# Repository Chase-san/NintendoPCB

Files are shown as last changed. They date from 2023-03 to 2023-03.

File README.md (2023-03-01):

# NintendoPCB

This repository is for the reproduction and documentation of various Nintendo PCBs. Specifically targeting the Gameboy series of handheld consoles.

# License

These boards are released under the Creative Commons Attribution-NonCommercial-ShareAlike 4.0 International License. See the LICENSE for more details.

In short, don't sell these designs or boards produced from these designs, and do attribute the designs to me.

# Gameboy GamePak PCB Designs

At present these are designed as repair boards for the official Nintendo Gameboy games. The intention is for the components from the original pcb to be transplanted directly to these boards. However a list of parts is made available if these are not otherwise available. These boards are designed to closely replicate the original tracks and fill zones of the original. These do NOT have the intention of fooling others into thinking they are official boards.

These are NOT designed to be used for Flash Carts, but rather to repair official games.
Please see HDR's [MBC3-Flashcart](https://github.com/HDR/MBC3-Flashcart) and [MBC30-Flashcart](https://github.com/HDR/MBC30-Flashcart) for PCB designs useful as flashcarts.

## Nintendo Board ID

Nintendo uses roughly the following system for producing the ID for a board.

`SYSTEM-ID-REVISION`

`SYSTEM` is either DMG or more rarely GBC, referring to the original Gameboy or the Gameboy Color.

`ID` is the actual ID of the board.

`REVISION` is the revision of the board. Most boards only have a single revision in the wild, but others, such as the DMG-BEAN have up to 6. Every revision I have seen has been electronically compatible with minor track, via, or fill differences.

## Differences from Official PCB

Each of these may have several revisions by Nintendo, I will usually try to base my board off the latest revision where possible. Despite this there are significant differences in design in a few regards compared to official PCBS.

### Debug Tracks and Holes

The Official PCBs make use of tracks which are interconnected, but which are then drilled out. I am unsure of the exact purpose of these, but they were likely for grounding purposes during manufacturing. Most of these have been removed as they serve no purposes for the repair board.
While it is possible that these extra tracks may allow special RF interactions, this does not appear to be by design.

### Thermal Relief

The Official PCBs make use of a different thermal relief pattern than KiCAD. Replicating the factory thermal relief pattern is possible but time consuming. Therefore these are often changed to the method KiCAD uses. Additionally some components may have had thermal relief added where it may be reasonable to do so.

### Identifying Marks

Some of these have been removed or altered.

- The revision number has been changed from a two digit number to "R#" where # is the repair board revision.
- The text "Repair Board" has been added near the board identifier.
- My initials and the year and month of the design have been added.
- Some non-informative identifying marks have been removed. Such as the large numbers on the front of the boards and the circle markers for the date identifier boxes.

### Tracks and Fill

While I make an effort to closely replicate the original board, some features may not be identical to the original. Some features are non-trivial to replicate and therefore an approximation has been used instead.

The main example of this being the battery fill which is fully circular on the repair boards.

## Ordering / Using the Gerber Files

I highly recommend using a service such as [JLCPCB](https://jlcpcb.com/) to get these manufactured. The following are the options that should be selected.

- Layers: 2
- Dimensions: 51mm x 60.7mm / 2" x 2.39"
- PCB Thickness: 0.8mm / 0.0315" (required)
- Surface Finish: ENIG or Hard Gold (required)
- Gold Fingers: Yes (required)
- Finger Chamfer: 45° (recommended)
- Copper Weight: 1 oz or higher (recommended)
- Color: Green (suggested), other colors have longer lead times

Of note, Hard Gold is very expensive so ENIG is a good option. The thicker the layer of gold the better the longer the pins will last. A heavier copper weight is nice but not required.

## Board List

These are the boards. Please check your original for the required one. Only boards with a revision number have a repair board developed.

Each folder related to this project is a distinct KiCAD project, containing subfolders with images of the repair board and scans of the original board it was based on.

This list is NOT exhaustive.

| Revision | ID | MBC | ROM | RAM | Battery | Other |
| :---: | :--- | :----: | :----: | :---: | :-----: | :--- |
| | CGB-A32  | MBC-6  | SOP-32 | SOP-28 | CR1616  | Flash |
| [R3](https://github.com/Chase-san/NintendoPCB/releases/tag/dmg-a02-r3) | DMG-A02  | MBC-5  | SOP-32 | SOP-28 | CR1616  | |
| | DMG-A03  | MBC-5  | TSOP2-44 | SOP-28 | CR1616  | |
| | DMG-A04  | MBC-5  | TSOP-32  | SOP-28 | CR1616  | Rumble |
| | DMG-A06  | MBC-5  | SOP-32 | SOP-28 | CR1616  | |
| | DMG-A07  | MBC-5  | SOP-32 | N/A | N/A | |
| | DMG-A08  | MBC-5  | TSOP2-44 | SOP-28 | CR1616  | |
| | DMG-A09  | MBC-5  | TSOP2-44 | N/A | N/A | |
| | DMG-A11  | MBC-5  | TSOP2-44 | SOP-28 | CR1616  | Rumble |
| | DMG-A14  | MBC-5  | TSOP2-44 | SOP-28 | CR2025  | |
| | DMG-A15  | MBC-5  | TSOP2-44 | SOP-28 | CR2025  | 2x ROM |
| | DMG-A16  | MBC-5  | SOP-32 | SOP-32 | CR2025  | |
| | DMG-A40  | MBC-7  | SOP-32 | N/A | N/A | Tilt/EEPROM  |
| | DMG-A47  | MBC-7  | TSOP2-44 | N/A | N/A | Tilt/EEPROM  |
| [R1](https://github.com/Chase-san/NintendoPCB/releases/tag/dmg-aaa-r1) | DMG-AAA  | N/A | MQFP-44  | N/A | N/A | |
| | DMG-BBA  | MBC-1  | SOIC-24  | N/A | N/A | |
| | DMG-BEAN | MBC-1  | SOP-32 | N/A | N/A | |
| | DMG-BFAN | MBC-1  | SOP-32 | N/A | N/A | |
| | DMG-DECN | MBC-1  | SOP-32 | SOP-28 | CR1616  | |
| | DMG-DEDN | MBC-1  | SOP-32 | SOP-28 | CR1616  | |
| | DMG-DGCU | MBC-1  | TSOP2-44 | SOP-28 | CR1616  | |
| [R1](https://github.com/Chase-san/NintendoPCB/releases/tag/dmg-gdan-r1) | DMG-GDAN | MBC-2  | SOP-32 | SOP-28 | CR1616  | |
| | DMG-KECN | MBC-3  | SOP-32 | SOP-28 | CR2025  | Clock |
| | DMG-KFCN | MBC-3  | SOP-32 | SOP-28 | CR2025  | Clock |
| | DMG-KFDN | MBC-3  | SOP-32 | SOP-28 | CR2025  | Clock |
| [R4](https://github.com/Chase-san/NintendoPCB/releases/tag/dmg-kgdu-r4) | DMG-KGDU | MBC-3  | TSOP2-44 | SOP-28 | CR2025  | Clock |
| | DMG-LFDN | MBC-3  | SOP-32 | SOP-28 | CR2025  | Clock |
| | DMG-MHEU | MBC-30 | TSOP2-44 | SOP-28 | CR2025  | Clock |
| | DMG-TEDN | HuC-1  | SOP-32 | SOP-28 | CR1616  | IR |
| | DMG-TFDN | HuC-1  | SOP-32 | SOP-28 | CR1616  | IR |
| | DMG-UEDT | HuC-3  | TSOP1-32 | TSOP1-28 | CR2025  | IR/Clock |
| | DMG-UFDT | HuC-3  | TSOP1-32 | TSOP1-28 | CR2025  | IR/Clock |
| | DMG-UGDU | HuC-3  | TSOP2-44 | TSOP1-28 | CR2025  | IR/Clock |
| | DMG-Z02  | MBC-5  | SOP-32 | SOP-28 | CR1616  | |
| | DMG-Z03  | MBC-5  | TSOP2-44 | SOP-28 | CR1616  | |
| | DMG-Z04  | MBC-5  | TSOP2-44 | SOP-28 | CR1616  | Rumble |

# Game Usage

Here is a list of the primary games using the given boards. Some boards have a lot of games or the game that uses the board is not particularly popular. Some games have used multiple boards (mostly pokemon).

| ID | Main Usage  |
| :---  | :---  |
| CGB-A32 | Net de Get - Minigame @ 100 (Japan) |
| DMG-A02 | Pokemon Red/Blue, Lots of other games. |
| DMG-A03 | Wario Land 2/3 |
| DMG-A04 | Pokemon Pinball |
| DMG-A06 | Game & Watch, Mega Man Xtreme 2 |
| DMG-A07 |  |
| DMG-A08 | TLOZ: Oracle of Ages/Seasons  |
| DMG-A09 | Rayman, Tony Hawk Pro Skater 2 |
| DMG-A11 | Pokemon Pinball  |
| DMG-A14 |  |
| DMG-A15 |  |
| DMG-A16 |  |
| DMG-A40 | Kirby Tilt & Tumble  |
| DMG-A47 |  |
| DMG-AAA | Catrap, Dr. Mario, Tetris  |
| DMG-BBA |  |
| DMG-BEAN  | Mega Man II-V, Pacman |
| DMG-BFAN  | Mortal Kombat I/II |
| DMG-DECN  | Donkey Kong, Donkey Kong Land, Super Mario Land 2  |
| DMG-DEDN  | Pocket Monsters Aka, Midori (Japan) |
| DMG-DGCU  | Dragon Quest Monsters  |
| DMG-GDAN  | Kirby's Pinball Land |
| DMG-KECN  | Bokujou Monogatari GB  |
| DMG-KFCN  | Mary Kate & Ashley Pocket Planner |
| DMG-KFDN  | Pokemon Gold/Silver/Crystal  |
| DMG-KGDU  | Pokemon Gold/Silver/Crystal  |
| DMG-LFDN  | Pocket Monsters Pikachu (Japan) |
| DMG-MHEU  | Pokemon Crystal (Japan)  |
| DMG-TEDN  | Pocket Bomber Man (Japan) |
| DMG-TFDN  | Pokemon Card GB (Japan) |
| DMG-UEDT  | Pocket Family GB  |
| DMG-UFDT  | Pocket Family GB  |
| DMG-UGDU  | Pocket Family GB 2  |
| DMG-Z02 | Mega Man Xtreme |
| DMG-Z03 |  |
| DMG-Z04 | Pokemon Pinball  |

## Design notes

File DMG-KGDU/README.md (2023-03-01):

# DMG-KGDU

This board is a repair board based on the DMG-KGDU-10. The DMG-KGDU is used by the USA versions of Pokemon Gold, Silver, and Crystal.

The original featured cut holes that were used for debugging purposes, these have been omitted.

This board was designed to closely replicate the footprints and routes used by the original cartridge board. All components may be sourced from an original cart.

## Components

This board features a 44-pin ROM and a 28-pin RAM module.

| Ref | Package | Description  | Notes | 
| :---: | :---: | :--- | :---- |
| U1 | TSOP-II-44W | Program ROM  | ~10.1mm wide |
| U2 | LQFP-32 | MBC-3 | |
| U3 | SOIC-28W | SRAM | ~8.3mm wide |
| U4 | SOIC-8 | System Reset | ~4.3mm wide |
| C1,C2 | 0603 (in) | 15pF Capacitor | |
| C3, C4, C5, C6 | 0603 (in) | 15nF Capacitor | Anything up to 0.1μF is supproted |
| R1 | 0603 (in) | 1kOhm Resistor | |
| R2 | 0603 (in) | 330kOhm Resistor | |
| X1 | 6mm x 2mm | 32.768 kHZ Cystal | 12.5 pF Load and 35 kOhm ESR |

## Change Log

### R4 (2023-02-03)
- Fillet the tracks
- Fix teardrops
- Fix various pad connections.

### Rev3 (2023-01-29)
- Added teardrops to vias and pins. Should help in fabs with lower standards, they also look nicer.
- Modified the X1 no copper zone to better reflect the original boards.
- Rounded the corners of the X1 cutout to be easier to manufacture.
- Removed the last of the silk screen.

### Rev2 (2023-01-21)
- Board redesigned based on high resolution scans.

### Rev1 (2023-01-20)
- Initial build based on photos.

## Images
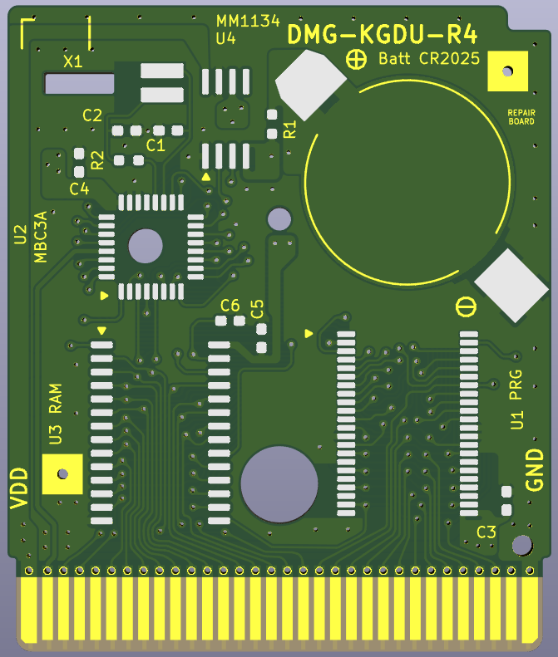
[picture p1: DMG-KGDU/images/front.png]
Front

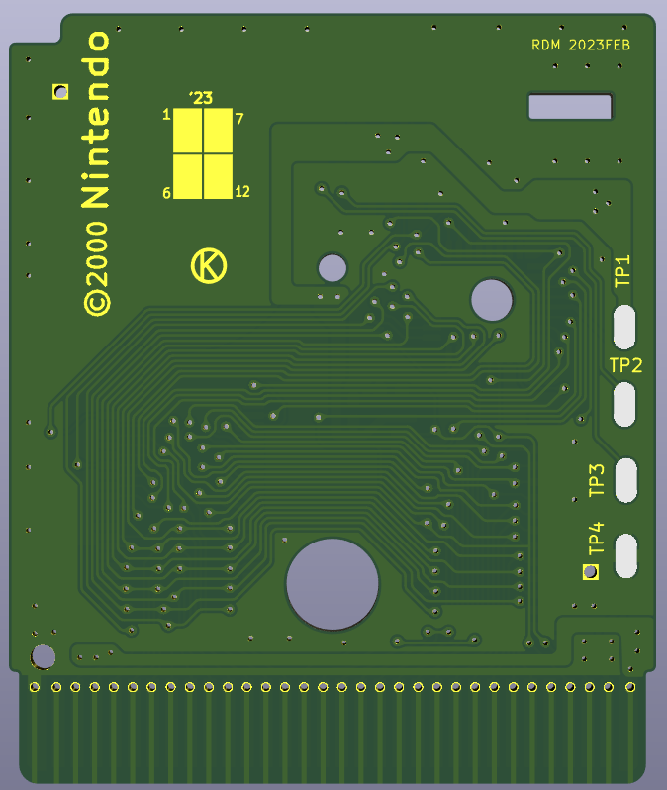
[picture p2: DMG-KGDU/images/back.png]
Rear


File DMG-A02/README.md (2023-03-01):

# DMG-A02

This board is a repair board based on the DMG-A02-10. The DMG-A02 is used by german versions of Pokemon Red/Blue, as well as Pokemon Yellow, Pokemon Trading Card Game, and Link's Awakening DX.

The original featured cut holes that were used for debugging purposes, most of these have been omitted.

This board was designed to closely replicate the footprints and routes used by the original cartridge board. All components may be sourced from an original cart.

## Components

This board features a 32-pin ROM and a 28-pin RAM module.

| Ref | Package | Description  | Notes | 
| :---: | :---: | :--- | :---- |
| U1 | SSOP-32W | Program ROM  | ~11mm wide |
| U2 | LQFP-32 | MBC-5 | |
| U3 | SOIC-28W | SRAM | ~8.3mm wide |
| U4 | SOIC-28 | System Reset | ~4.3mm wide |
| C1, C2, C3, C4 | 0603 (in) |  0.015uF - 0.1uF Capacitor | |
| C5 | 0603 (in) | Empty | |
| C6 | 0603 (in) | 33pF Capacitor | May be left empty |
| R1 | 0603 (in) | 1kOhm Resistor | |

## Change Log

### R4 (2023-02-13)
- Added teardrop to pin pads.
- Adjusted MBC cutout
- Other minor changes

### R3 (2023-01-23)
- Added teardrops to via.
- Fillet tracks
- Added MBC hole

### Rev2 (2023-01-21)
- Fixed rear GND Test pad.

### Rev1 (2023-01-20)
- Initial build

## Images
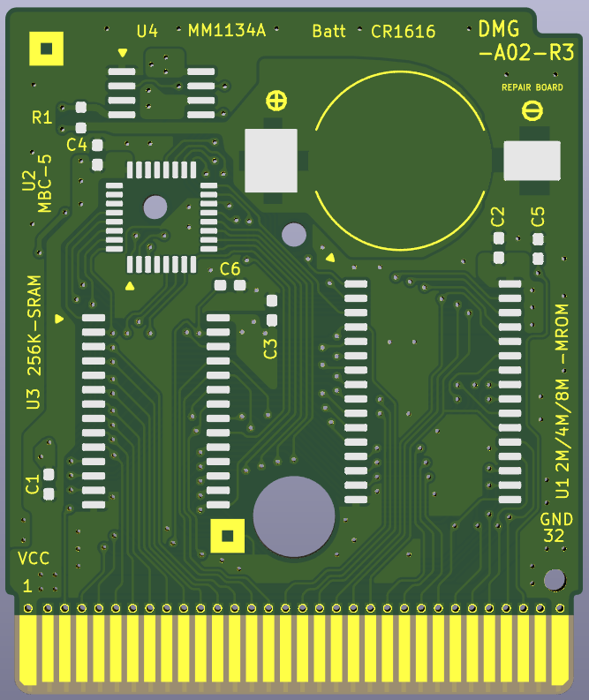
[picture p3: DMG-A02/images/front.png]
Front

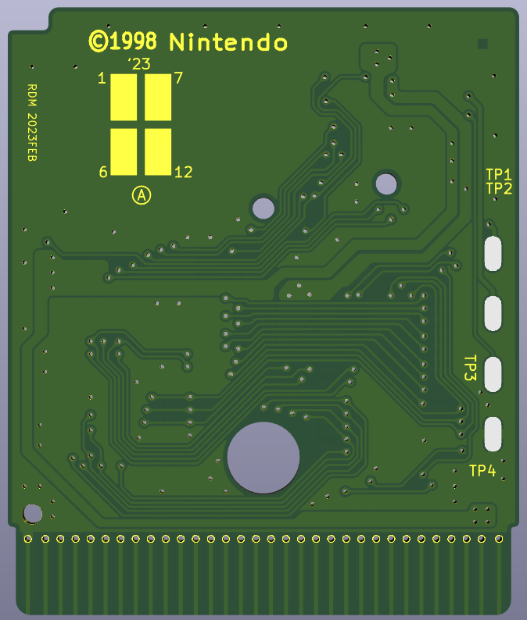
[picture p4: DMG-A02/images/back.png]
Rear


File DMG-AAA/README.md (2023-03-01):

# DMG-AAA

This board is a repair board based on the DMG-AAA-02. The DMG-AAA is used by Catrap, Dr. Mario, and most versions of Tetris.

This board does not feature a MBC at all, and only has a ROM chip.

The original featured cut holes that were used for debugging or reference purposes, these have been mostly preserved.

This board was designed to closely replicate the footprints and routes used by the original cartridge board.

## Components

This board features a 44-pin ROM.

| Ref | Package | Description  | Notes | 
| :---: | :---: | :--- | :---- |
| U1 | MQFP-44 | Program ROM  | |
| C1 | Axial 3.8mm x 2mm | 10nF ±10% Capacitor | Might be empty |
| C2 | Radial 6.8mm x 2.8mm | | Usually Empty |

## Change Log

### R2 (2023-02-03)
- Added missing pointer.

### R1 (2023-02-02)
- Initial build

## Images
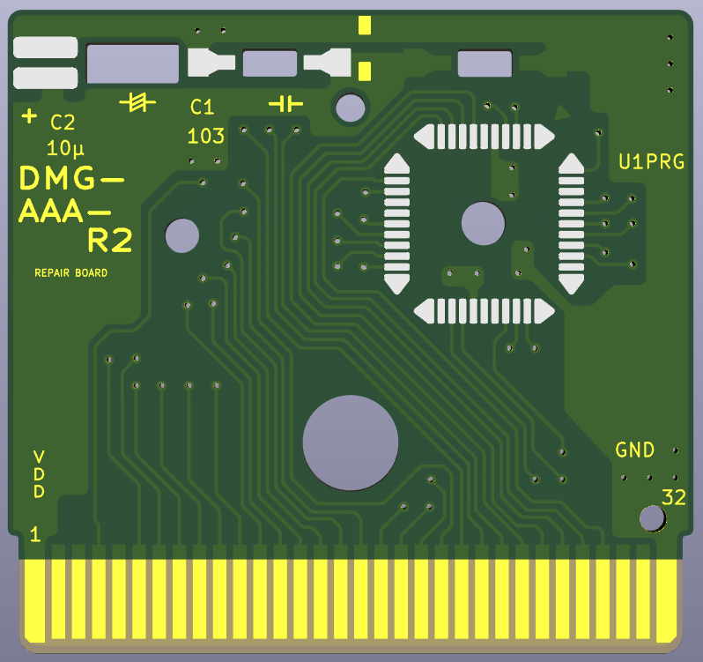
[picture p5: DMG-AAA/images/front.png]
Front

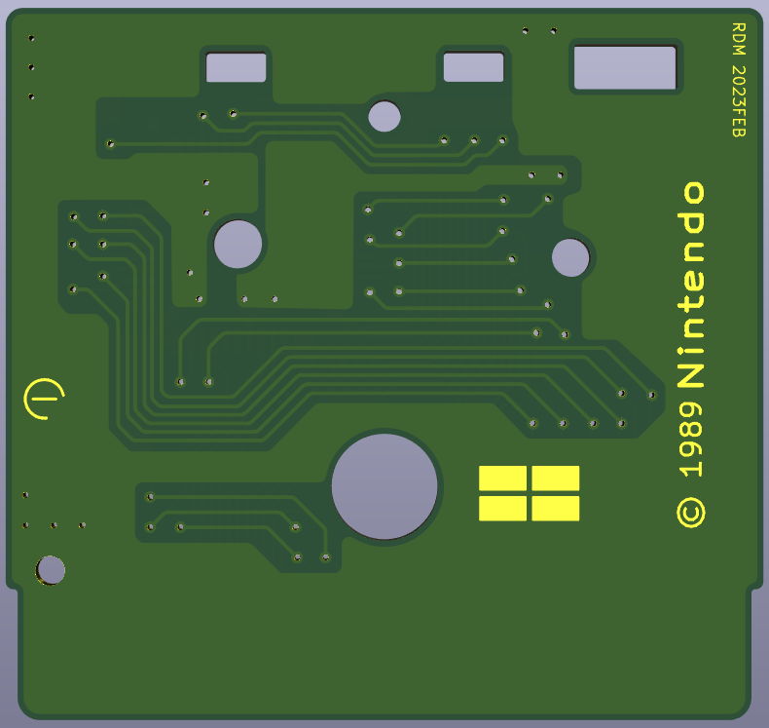
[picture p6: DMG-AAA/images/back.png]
Rear


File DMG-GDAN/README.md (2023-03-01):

# DMG-GDAN-10

This board is a repair board based on the DMG-GDAN-10. The DMG-GDAN is used by F-1 Race, Kirby's Pinball Land, and Ultra Golf.

Unlike the other memory controllers, the MBC2 has ram onboard, preventing the need for an additional RAM chip. This board was mainly used by games that needed saves, but not much additional ram.

The original featured cut holes that were used for debugging or reference purposes, these have been omitted.

This board was designed to closely replicate the footprints and routes used by the original cartridge board.

## Components

This board features a 32-pin ROM. Like many boards before the MBC-3 this one features components that can be both axial/radial or SMD.

| Ref | Package | Description  | Notes | 
| :---: | :---: | :--- | :---- |
| U1 | SOP-32 | Program ROM  | |
| U2 | SOIC-28W | MBC-2 | |
| U3 | SOIC-28 | System Reset | |
| C1 | Axial & 0603 | 10nF ±10% Capacitor | Only populate one |
| C2 | Axial & 0603 | 10nF ±10% Capacitor | Only populate one |
| C3 | Radial & 0603 | | Usually empty |
| R1 | Axial & 0603 | 10K Ohm 5% Resistor | Only populate one |

## Change Log

### R1 (2023-02-02)
- Initial build

## Images
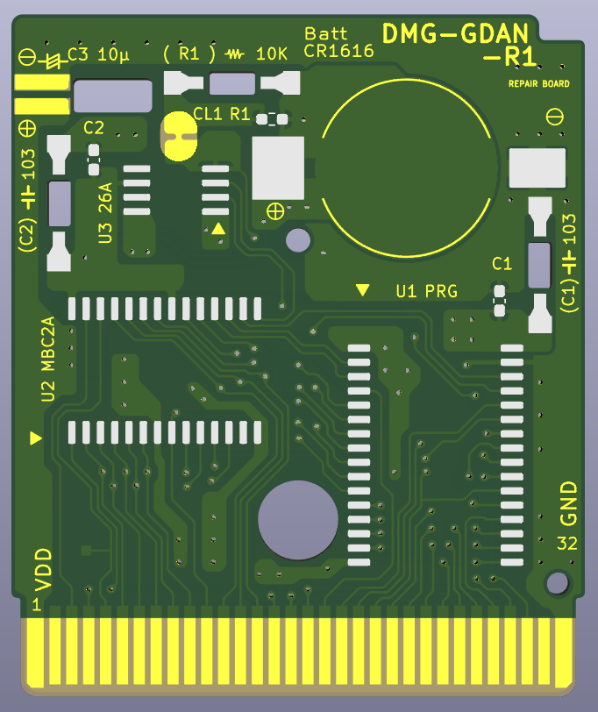
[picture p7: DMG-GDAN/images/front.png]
Front

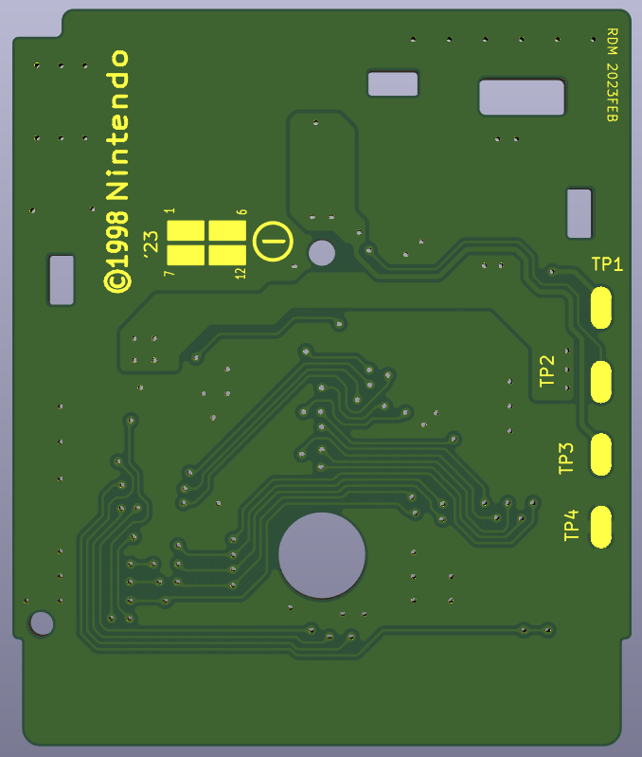
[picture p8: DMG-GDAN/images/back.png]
Rear


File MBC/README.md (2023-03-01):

# MBC
This is a selection of details on the memory bank controllers used by Gameboy and Gameboy Color games.

## Addressing
Read/Write subheaders are suffixed with a value in **[** and **]**, this value denotes the required values of the address bits, starting at A15 and proceeding downward.
Only bits available on the given MBC are shown. For example [010x] and [010] are functionally identical, but [010x] has the A12 address pin.

These values provide no additional information, but are a useful shorthand.

# MBC-3
128 switchable ROM banks (2MB, 7 bits).
4 switchable RAM banks (32kB, 2 bits).

## RTC
The MBC-3 contains an Real Time Clock (RTC) circuitry. There are a total of 5 RTC registers.

- **Register 0**: Seconds 0-59
- **Register 1**: Minutes 0-59
- **Register 2**: Hours 0-23
- **Register 3**: Day Counter
- **Register 4**: RTC Flags
  - **Bit 0**: Day Counter (Bit 9)
  - **Bit 6**: 0=RTC Active, 1=RTC Stopped (set to 1 before writing)
  - **Bit 7**: 0=Normal, 1=Day Counter Overflow

## Pinout

Pin Diagram

**Package:** LQFP-32

## Read
### 0000-3FFF [00x]
Read from Bank 0. (ROM)

### 4000-7FFF [01x]
Switchable ROM bank. Defaults to bank 1.
Can be swapped for any other bank except 0.
Bank is determined by ROM bank register.

### A000-BFFF [101]
External RAM or RTC register. Disabled by default.
Reads are FF when disabled.
Bank is determined by RAM bank register.

## Write
### 0xxx-1xxx [000]
Enable/Disable External RAM. xA enables, anything else disables.

### 2xxx-3xxx [001]
Set ROM bank register.

### 4xxx-5xxx [010]
Set RAM bank register. Values 0 to 7 select RAM bank. Values 8 and above select the RTC registers (starting at register 0).

### 6xxx-7xxx [011]
Writing `00` `01` here will latch or unlatch the RTC registers, which prevents them from changing.
The RTC will continue in the background. RTC registers should be latched before reading.

### A000-BFFF [101]
Write to RAM or RTC register, if enabled.

# MBC-30
An enhancement of the MBC3 used by Japanese Pokemon Crystal version. This functions identically to the MBC-3.
256 switchable ROM banks (4MB, 8 bits).
8 switchable RAM banks (64kB, 3 bits).

## Pinout

Pin Diagram

**Package:** LQFP-32

# MBC-5
512 switchable ROM banks (9 bits).
16 switchable RAM banks (4 bits).
External RAM enable/disable.

Requires 14 bits of volatile storage for these features.

## Pinout

Pin Diagram

**Package:** LQFP-32

## Read
### 0000-3FFF [00xx]
Read from Bank 0. (ROM)

### 4000-7FFF [01xx]
Switchable ROM bank. Defaults to bank 1.
Can be swapped for any other bank (including 0).
Bank is determined by ROM bank registers.

### A000-BFFF [101x]
External RAM. Disabled by default.
Reads are FF when disabled.
Bank is determined by RAM bank register.

## Write
### 0xxx-1xxx [000x]
Enable/Disable External RAM. xA enables, anything else disables.

### 2xxx [0010]
Set ROM bank low register. Values are 0-255.

### 3xxx [0011]
Set ROM bank high register. Values are 0-1. (not enough pins for anything more)

### 4xxx-5xxx [010x]
Set RAM bank register.

### A000-BFFF [101x]
Write to RAM if enabled.

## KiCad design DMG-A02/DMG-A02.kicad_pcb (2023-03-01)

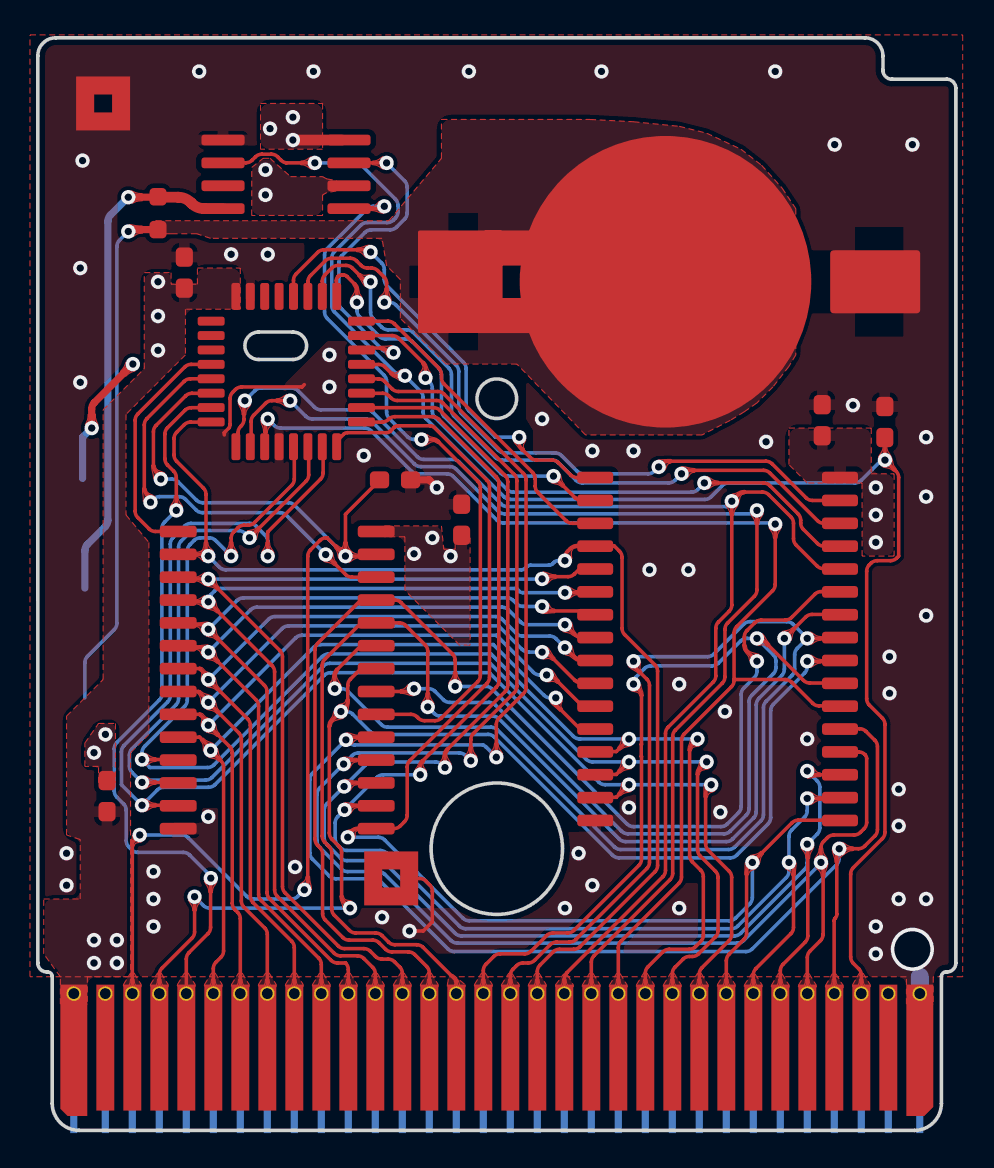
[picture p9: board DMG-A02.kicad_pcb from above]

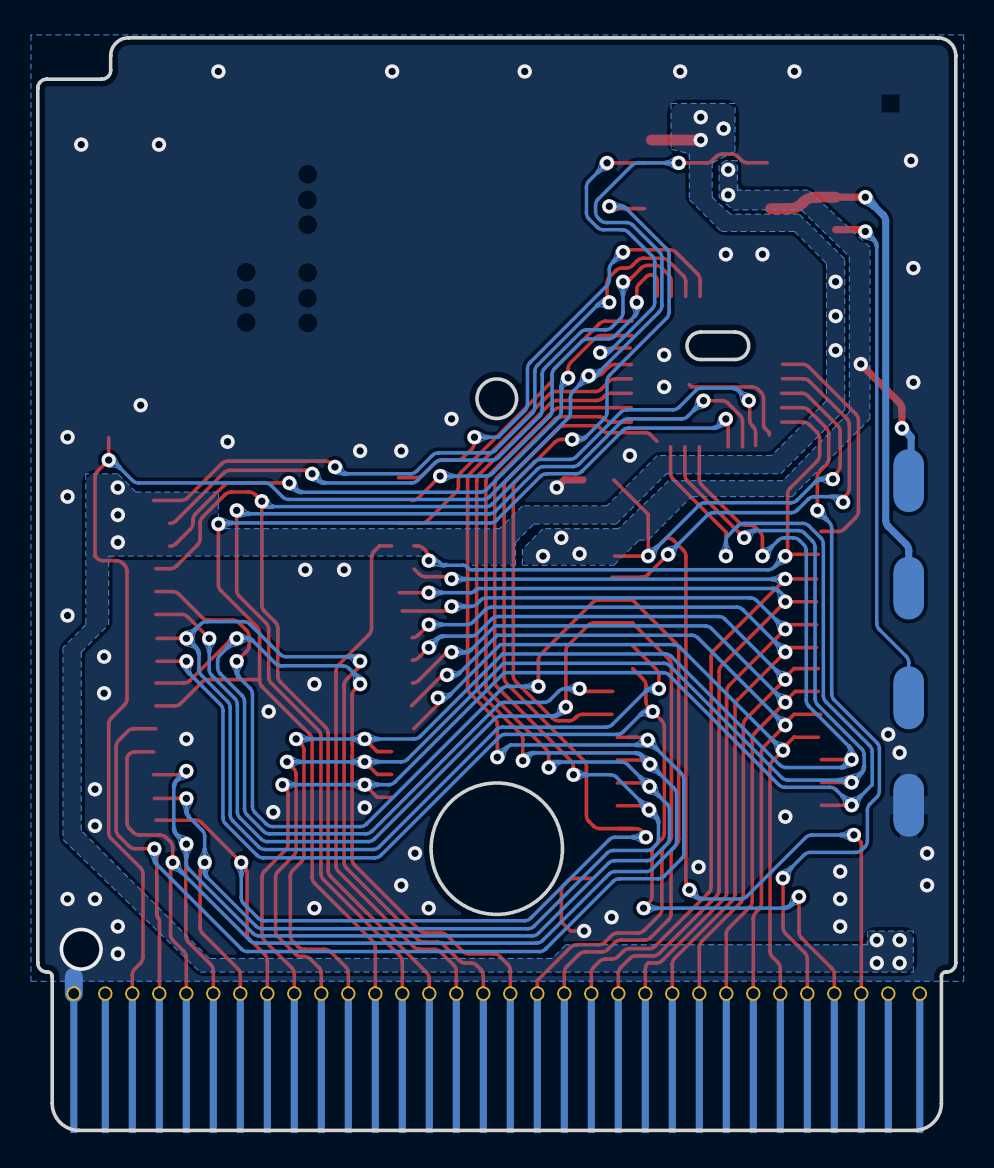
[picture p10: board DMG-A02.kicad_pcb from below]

Board: 2 copper layers, 51.0 x 60.7 mm, 19 parts (4 on the bottom side), 43 nets.

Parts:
BATT1: Batt_CR1616
C1, C2, C3, C4, C5, C6: 0.1uF; C_0603_Pad_HandSolder
G1, G2: GroundPad_Square_SMD_3mm
R1: 1kΩ; R_0603_Pad_HandSolder
TP1, TP2, TP3, TP4: TestPoint_3.5x1.7mm
U0: CartBus; GameBoy_GamePak_CGB-002_P1.50mm_Edge
U1: SSOP-32_MROM
U2: LQFP-32_MBC
U3: SOIC-28_SRAM
U4: SO-8_SYSRST

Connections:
A00: U0.6, U1.12, U3.10
A01: U0.7, U1.11, U3.9
A02: U0.8, U1.10, U3.8
A03: U0.9, U1.9, U3.7
A04: U0.10, U1.8, U3.6
A05: U0.11, U1.7, U3.5
A06: U0.12, U1.6, U3.4
A07: U0.13, U1.5, U3.3
A08: U0.14, U1.27, U3.25
A09: U0.15, U1.26, U3.24
A10: U0.16, U1.23, U3.21
A11: U0.17, U1.25, U3.23
A12: U0.18, U1.4, U2.32, U3.2
A13: U0.19, U1.28, U2.1
A14: U0.20, U2.2
A15: U0.21, U1.22, U2.3
BT+: BATT1.1, R1.1, TP3.1
CS: U0.5, U2.31
CS_EN: U2.14, U4.7
D0: U0.22, U1.13, U2.5, U3.11
D1: U0.23, U1.14, U2.6, U3.12
D2: U0.24, U1.15, U2.7, U3.13
D3: U0.25, U1.17, U2.8, U3.15
D4: U0.26, U1.18, U2.9, U3.16
D5: U0.27, U1.19, U2.10, U3.17
D6: U0.28, U1.20, U2.11, U3.18
D7: U0.29, U1.21, U2.12, U3.19
GND: BATT1.2, C1.2, C2.2, C3.2, C4.2, C5.2, C6.2, G1.1, G2.1, TP4.1, U0.32, U1.16, U2.4, U2.23, U3.14, U4.1
RA14: U1.29, U2.15
RA15: U1.3, U2.16
RA16: U1.2, U2.17
RA17: U1.30, U2.18
RA18: U1.31, U2.19
RA19: U1.1, U2.20
RAMCS: U3.20, U4.5
Read: U0.4, U1.24, U3.22
Reset: C5.1, U0.30, U2.13, U4.2
SA13: U2.29, U3.26
SA14: U2.28, U3.1
VBATT: R1.2, TP2.1, U4.4
VCC: C1.1, C2.1, C4.1, U0.1, U1.32, U2.24, U4.8
VOUT: C3.1, TP1.1, U3.28, U4.6
Write: C6.1, U0.3, U2.30, U3.27

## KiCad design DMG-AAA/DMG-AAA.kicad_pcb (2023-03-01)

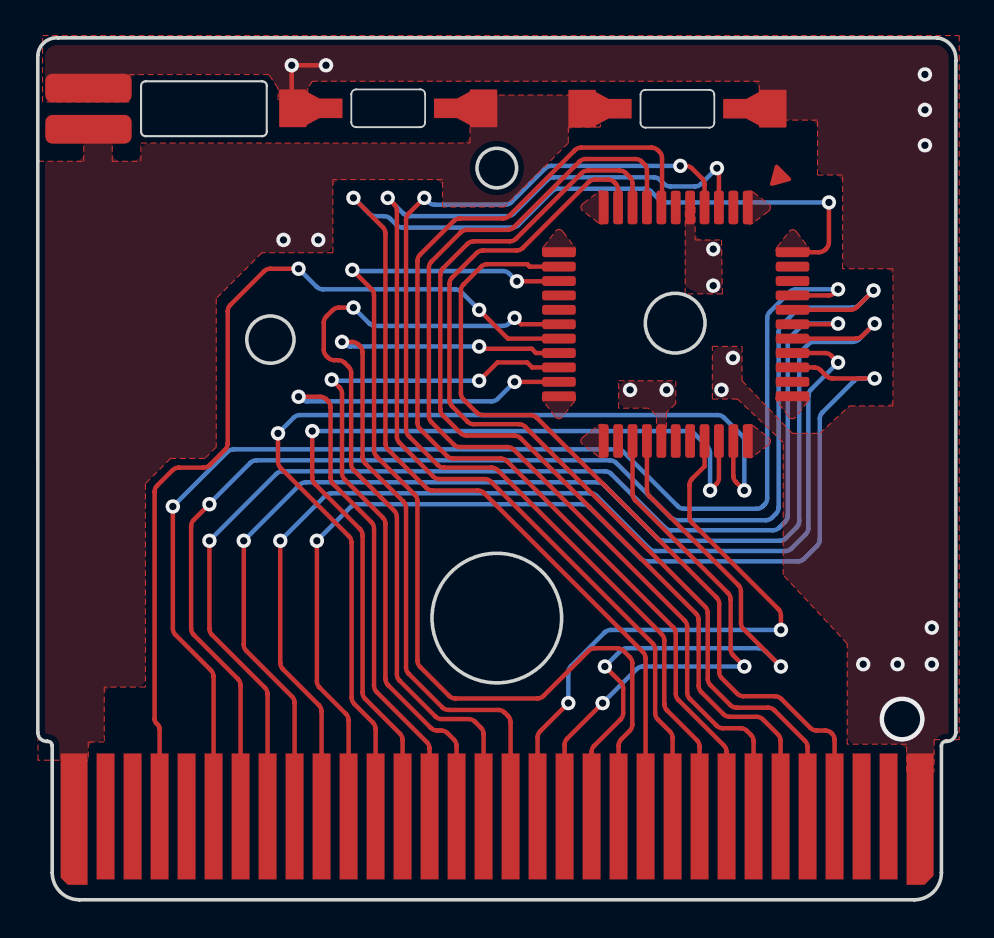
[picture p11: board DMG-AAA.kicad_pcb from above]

Board: 2 copper layers, 51.0 x 47.9 mm, 5 parts (0 on the bottom side), 27 nets.

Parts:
C1, C1#2: Capacitor_SMD_Axial_4mm; Capacitor_SMD_Axial_4mm_2mm
C2: C_Radial_Pad_7mm_x_3mm
U0: CartBus; Connector_Edge_GamePak_P1.50mm
U1: PRG; MQFP-44_10x10mm_P0.8mm

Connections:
A00: U0.6, U1.41
A01: U0.7, U1.40
A02: U0.8, U1.39
A03: U0.9, U1.38
A04: U0.10, U1.37
A05: U0.11, U1.36
A06: U0.12, U1.32
A07: U0.13, U1.31
A08: U0.14, U1.21
A09: U0.15, U1.20
A10: U0.16, U1.17
A11: U0.17, U1.19
A12: U0.18, U1.30
A13: U0.19, U1.25
A14: U0.20, U1.26
A15: U0.21, U1.14
D0: U0.22, U1.44
D1: U0.23, U1.3
D2: U0.24, U1.4
D3: U0.25, U1.7
D4: U0.26, U1.8
D5: U0.27, U1.9
D6: U0.28, U1.10
D7: U0.29, U1.13
GND: C1.2, C1#2.1, C2.1, U0.32, U1.5
VCC: C1.1, C1#2.2, C2.2, U0.1, U1.27
~RD: U0.4, U1.18

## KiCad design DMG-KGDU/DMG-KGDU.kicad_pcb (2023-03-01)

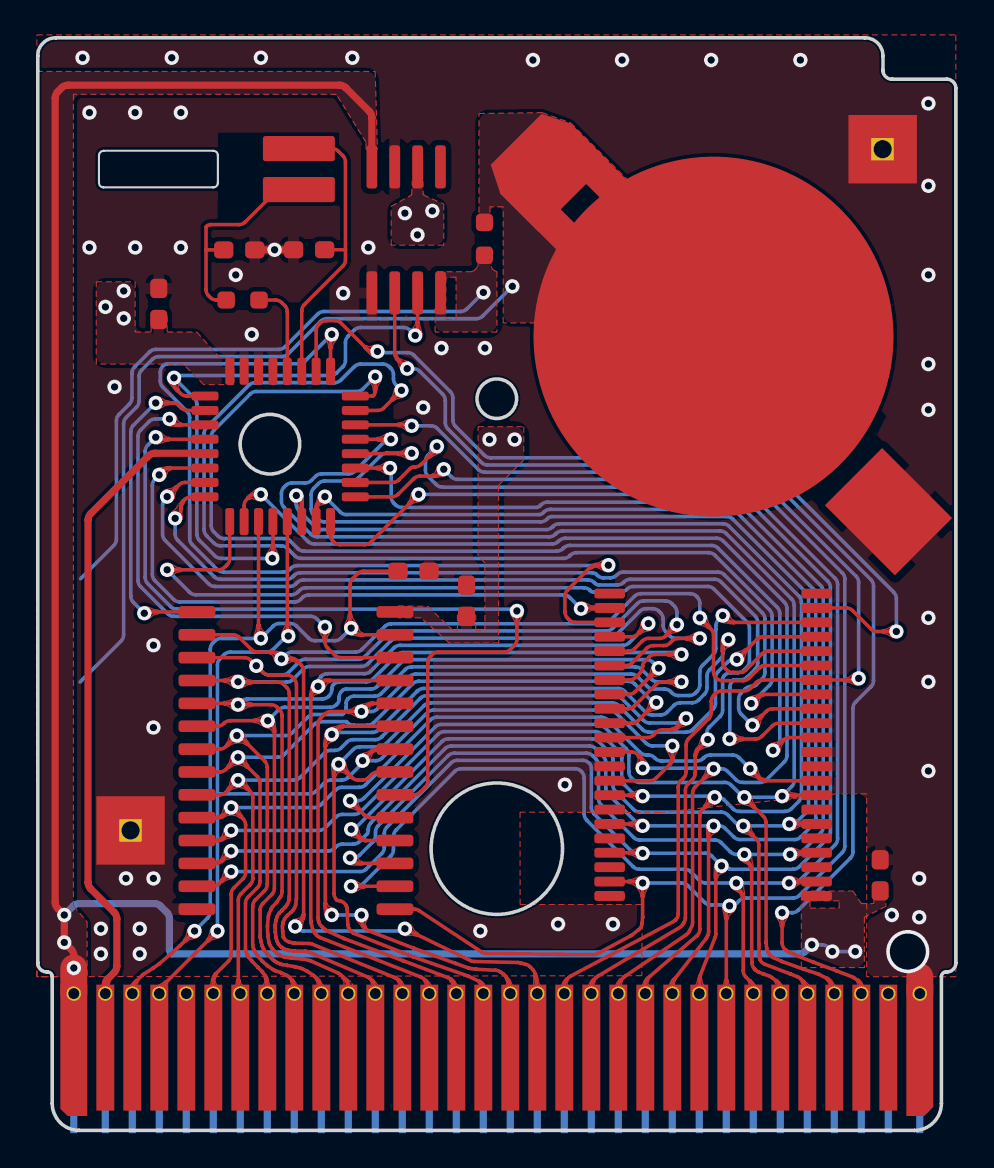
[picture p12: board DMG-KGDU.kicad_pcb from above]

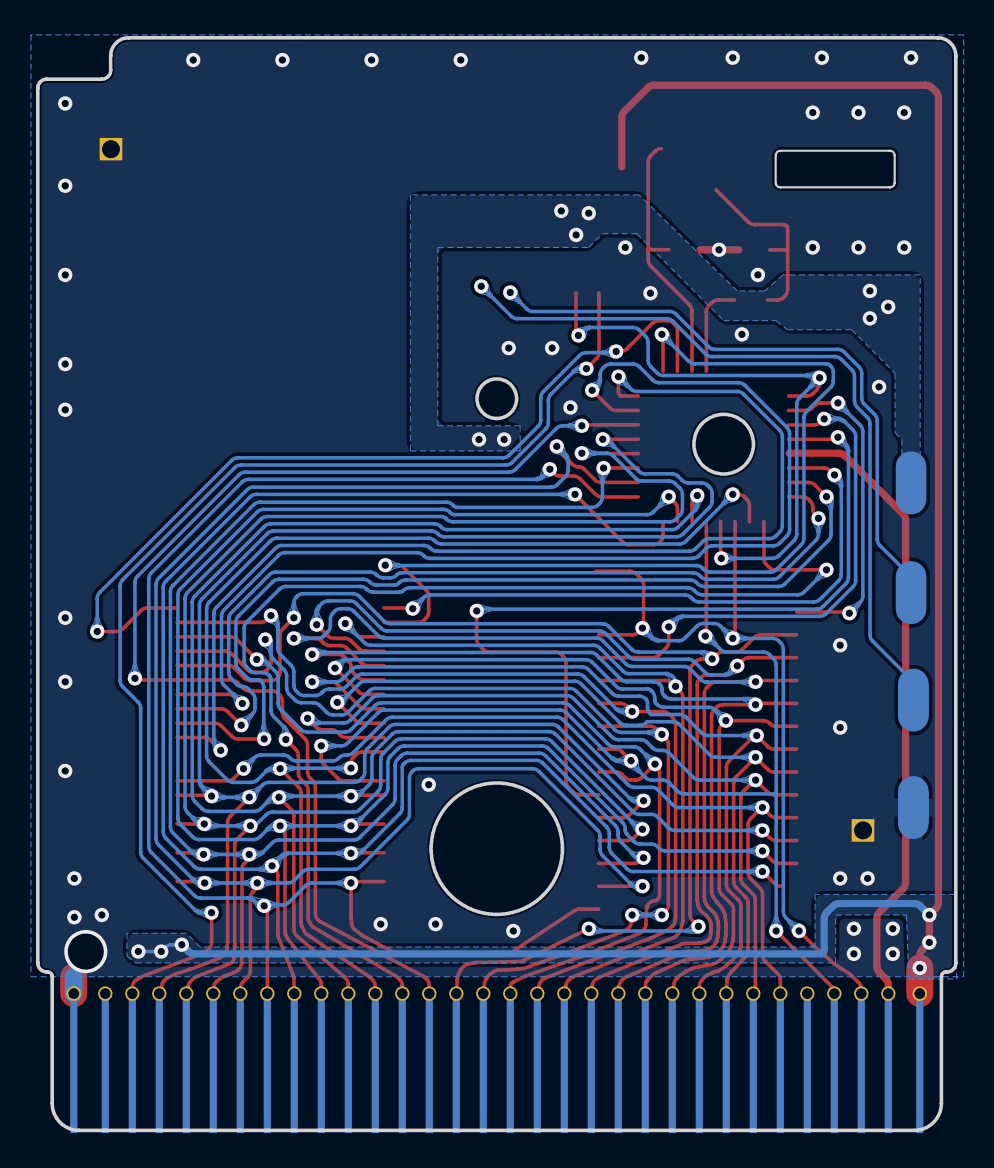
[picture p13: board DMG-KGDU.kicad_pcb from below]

Board: 2 copper layers, 51.0 x 60.7 mm, 21 parts (4 on the bottom side), 47 nets.

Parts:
BT1: Batt CR2025; Batt_CR2025
C1, C2: 15pF; C_0603_Pad_HandSolder
C3, C4, C5, C6: 0.1pF; C_0603_Pad_HandSolder
GND1, GND2: GroundPad_Square_TH_3.8mm
R1: 1kΩ; R_0603_Pad_HandSolder
R2: 330kΩ; R_0603_Pad_HandSolder
TP1, TP2, TP3, TP4: TestPoint_3.5x1.7mm
U0: CartBus; GameBoy_GamePak_CGB-002_P1.50mm_Edge
U1: PRG; TSOP-II-44_MROM
U2: MBC3A; LQFP-32_MBC
U3: RAM; SOIC-28_SRAM
U4: MM1134; SO-8_SYSRST
X1: Crystal_D2mm_L6mm_Horizontal

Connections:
A00: U0.6, U1.31, U3.10
A01: U0.7, U1.11, U3.9
A02: U0.8, U1.10, U3.8
A03: U0.9, U1.9, U3.7
A04: U0.10, U1.8, U3.6
A05: U0.11, U1.7, U3.5
A06: U0.12, U1.6, U3.4
A07: U0.13, U1.5, U3.3
A08: U0.14, U1.4, U3.25
A09: U0.15, U1.42, U3.24
A10: U0.16, U1.41, U3.21
A11: U0.17, U1.40, U3.23
A12: U0.18, U1.39, U3.2
A13: U0.19, U1.38, U2.14
A14: U0.20, U2.1
A15: U0.21, U1.12, U2.2
AA13: U2.27, U3.26
AA14: U2.26, U3.1
BT+: BT1.1, R1.2, TP3.1
CE: U2.28, U3.20
Clock: U0.2, U2.29
D0: U0.22, U1.15, U2.6, U3.11
D1: U0.23, U1.17, U2.7, U3.12
D2: U0.24, U1.19, U2.8, U3.13
D3: U0.25, U1.21, U2.9, U3.15
D4: U0.26, U1.24, U2.10, U3.16
D5: U0.27, U1.26, U2.11, U3.17
D6: U0.28, U1.28, U2.12, U3.18
D7: U0.29, U1.30, U2.13, U3.19
GND: BT1.2, C1.1, C2.2, C3.2, C4.2, C5.2, C6.2, GND1.1, GND2.1, TP4.1, U0.32, U1.13, U1.32, U1.33, U2.22, U2.23, U3.14, U4.1, U4.7
RA14: U1.37, U2.15
RA15: U1.36, U2.32
RA16: U1.35, U2.31
RA17: U1.34, U2.16
RA18: U1.3, U2.17
RA19: U1.2, U2.30
RA20: U1.43, U2.18
Read: U0.4, U1.14, U2.5, U3.22
Reset: U0.30, U4.2
SYS_RST: U2.4, U2.25, U4.3
VBATT: R1.1, TP2.1, U4.4
VCC: C3.1, U0.1, U1.23, U4.8
VOUT: C4.1, C5.1, TP1.1, U2.24, U3.28, U4.6
Write: C6.1, U0.3, U2.3, U3.27
XIN: C1.2, U2.19, X1.1
XOUT: R2.2, U2.20
X_: C2.1, R2.1, X1.2

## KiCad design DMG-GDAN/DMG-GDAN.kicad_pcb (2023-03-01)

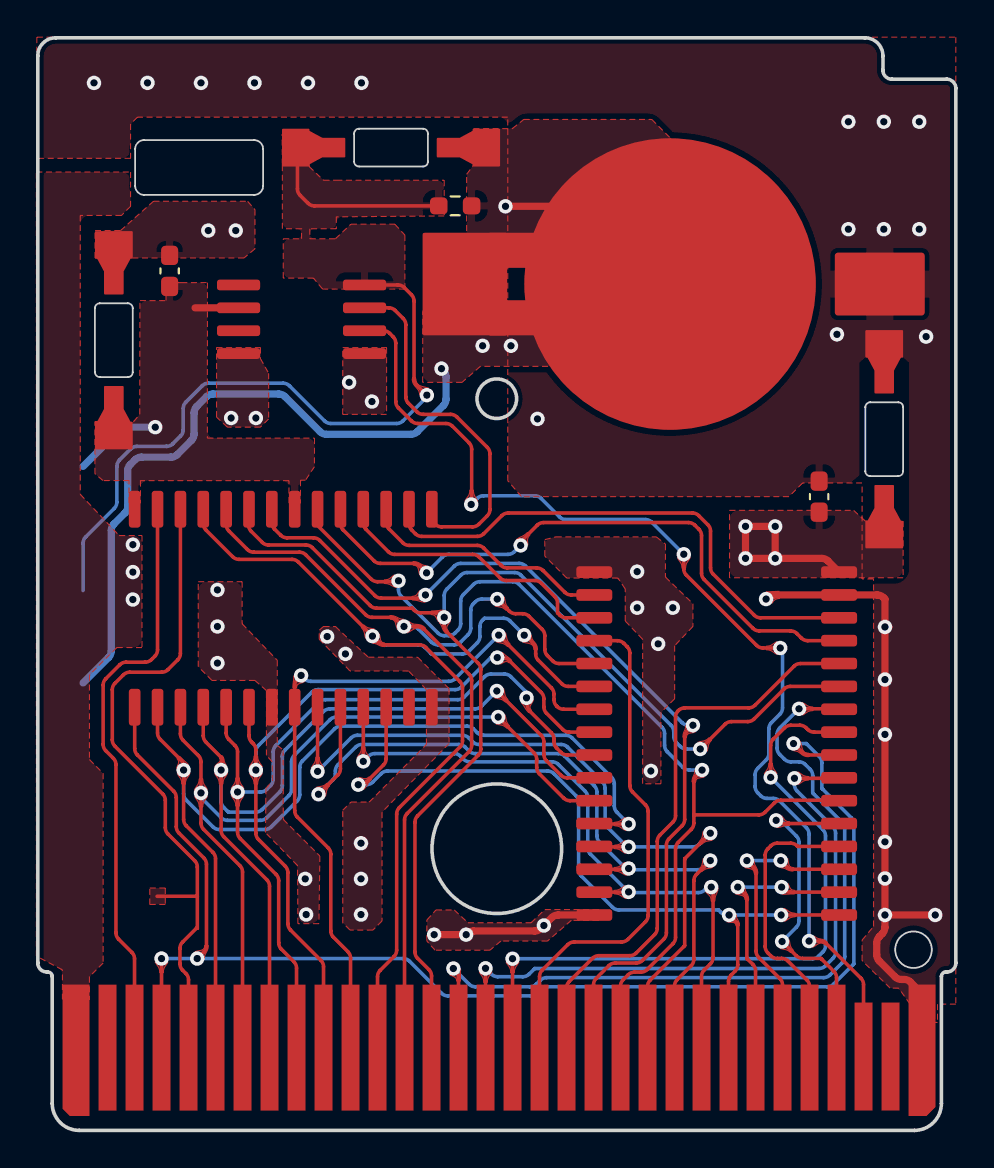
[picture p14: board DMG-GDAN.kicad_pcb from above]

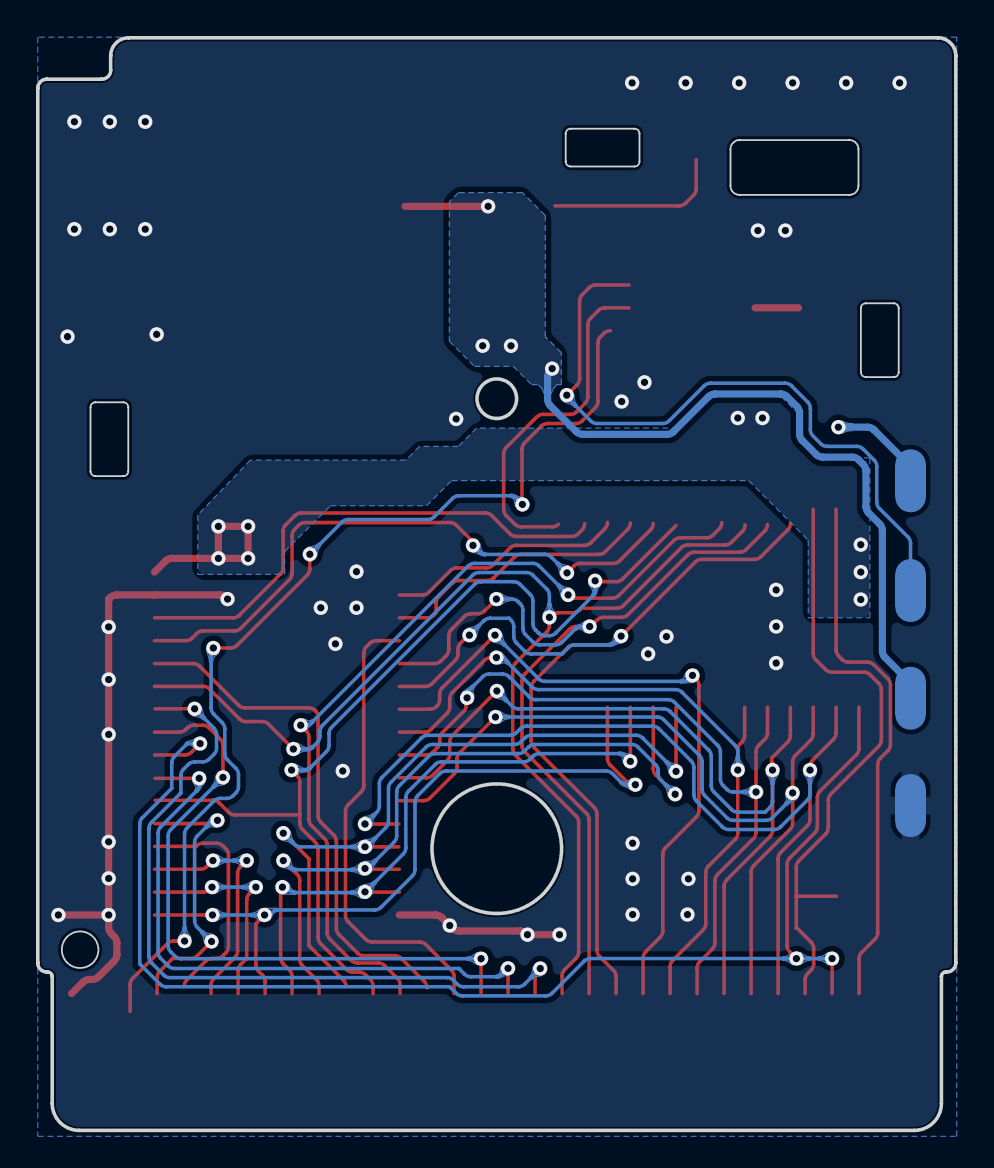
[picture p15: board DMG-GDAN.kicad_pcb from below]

Board: 2 copper layers, 51.0 x 60.7 mm, 15 parts (4 on the bottom side), 38 nets.

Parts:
( R1 ): Resistor_SMD_Axial_4mm_2mm
(C1), (C2): Capacitor_SMD_Axial_4mm; Capacitor_SMD_Axial_4mm_2mm
Batt: CR1616; Batt_CR1616
C1, C2: C_0603_1608Metric_Pad1.08x0.95mm_HandSolder
R1: R_0603_1608Metric_Pad0.98x0.95mm_HandSolder
TP1, TP2, TP3, TP4: TestPoint_3.5x1.7mm
U0: CartBus; Connector_Edge_GamePak_P1.50mm
U1: PRG; SSOP-32_MROM
U2: MBC2A; SOIC-28_SRAM
U3: 26A; SO-8_SYSRST

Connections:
A00: U0.6, U1.12, U2.2
A01: U0.7, U1.11, U2.3
A02: U0.8, U1.10, U2.4
A03: U0.9, U1.9, U2.5
A04: U0.10, U1.8, U2.6
A05: U0.11, U1.7, U2.8
A06: U0.12, U1.6, U2.25
A07: U0.13, U1.5, U2.24
A08: U0.14, U1.27, U2.23
A09: U0.15, U1.26
A10: U0.16, U1.23
A11: U0.17, U1.25
A12: U0.18, U1.4
A13: U0.19, U1.28
A14: U0.20, U2.22
A15: U0.21, U1.22, U2.20
BT+: ( R1 ).2, Batt.1, R1.2, TP3.3
CS: U0.5, U2.26
CS_U3: U2.15, U3.3
D0: U0.22, U1.13, U2.9
D1: U0.23, U1.14, U2.10
D2: U0.24, U1.15, U2.11
D3: U0.25, U1.17, U2.12
D4: U0.26, U1.18
D5: U0.27, U1.19
D6: U0.28, U1.20
D7: U0.29, U1.21
GND: (C1).2, (C2).2, Batt.2, C1.2, C2.2, TP4.4, U0.32, U1.1, U1.16, U1.31, U2.7, U2.14, U3.1
RA14: U1.29, U2.19
RA15: U1.3, U2.18
RA16: U1.2, U2.17
RA17: U1.30, U2.16
VBAT: ( R1 ).1, R1.1, TP2.2, U3.4
VCC: (C1).1, C1.1, U0.1, U1.32, U3.8
VOUT: (C2).1, C2.1, TP1.1, U2.21, U2.28, U3.6
/RD: U0.4, U1.24, U2.1
/RST: U0.30, U3.2
/WR: U0.3, U2.27

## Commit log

2023-03-01 Remake due to GIT-LFS issues
    [DMG-A02.kicad_pcb, DMG-AAA.kicad_pcb, DMG-GDAN.kicad_pcb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]
2023-03-01 Update capacitor values.
2023-03-01 Fix D3 arc issue
    [DMG-A02.kicad_pcb]
2023-03-01 Update timestamp.
    [DMG-A02.kicad_pcb]

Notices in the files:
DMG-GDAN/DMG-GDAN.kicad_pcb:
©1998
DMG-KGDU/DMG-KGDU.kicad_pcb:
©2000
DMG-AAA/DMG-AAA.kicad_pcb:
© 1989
